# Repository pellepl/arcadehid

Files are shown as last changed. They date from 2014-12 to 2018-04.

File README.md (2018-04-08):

arcadehid
=========

STM32 HID device for arcade builds

Compound HID device containing keyboard, mouse, two joysticks and a virtual com port. Plug into a retropie or something and wire cool buttons and joysticks and whatnot.

See /cad - here you'll find a reference design with 26 pins for an STM32F1 128kB flash variant. Any STM32F1 board would do, as long as pin-headers are broken out.

Each pin can be configured with combinations of a keyboard keypress, mouse movement or click, or joystick movement or button press.

Every pin can hold up to eight different combinations. There is also ternary support meaning a pin's config can change depending on if another pin is active or not.

Accelerators for mouse and joystick are supported.

Everything is configured in the command line interface, either via UART pins or via virtual com port.

Different configurations can be saved and loaded, using the internal flash of the STM32F1 (128 kb variant) - no extra storage chip needed.

Depends on pellepl/generic_embedded and pellepl/niffs.

Now also with the Annoyatron support, drive your friends mad...

CLI pin definition examples
===========================
```
// define pin 1 to send keyboard character A
def pin1 = a
// define pin 2 to move mouse up
def pin2 = mouse_y(-1)
// define pin 3 to move mouse right if pin 4 is pressed else left
def pin3 = pin4 ? mouse_x(1) : mouse_x(-1)
// define pin 5 to send keyboard sequence CTRL+ALT+DEL
def pin5 = LEFT_CTRL LEFT_ALT DELETE
```

For certain definitions, numerators are possible. A numerators normally tells how much to move something, e.g. a mouse or joystick. In addition, all numerators can have accelerators, meaning the control will move more and more over time.
A numerator ```<num>``` is defined as  ```(ACC)[(+)|-][1..127]```.

```
// move joystick 10 steps right on x axis
def pin7 = joy1_x(10)
// move joystick accelerating from 1 to 10 steps right on x axis
def pin8 = joy1_x(ACC10)
// and left
def pin8 = joy1_x(ACC-10)
```

Accelerator speed is controlled by cli commands
```
set_mouse_pos_acc
set_mouse_wheel_acc
set_joy_acc
```

Following is a list of all definitions possible.

```
KEYBOARD SYMBOLS:
  A                   B                   C                   D                   
  E                   F                   G                   H                   
  I                   J                   K                   L                   
  M                   N                   O                   P                   
  Q                   R                   S                   T                   
  U                   V                   W                   X                   
  Y                   Z                   1                   2                   
  3                   4                   5                   6                   
  7                   8                   9                   0                   
  ENTER               ESCAPE              BACKSPACE           TAB                 
  SPACE               MINUS               EQUAL               LEFTBRACKET         
  RIGHTBRACKET        BACKSLASH           NONUS_HASH          SEMICOLON           
  QUOTE               GRAVE               COMMA               DOT                 
  SLASH               CAPSLOCK            F1                  F2                  
  F3                  F4                  F5                  F6                  
  F7                  F8                  F9                  F10                 
  F11                 F12                 PRINTSCREEN         SCROLLLOCK          
  PAUSE               INSERT              HOME                PGUP                
  DELETE              END                 PGDOWN              RIGHT               
  LEFT                DOWN                UP                  NUMLOCK             
  KP_SLASH            KP_ASTERISK         KP_MINUS            KP_PLUS             
  KP_ENTER            KP_1                KP_2                KP_3                
  KP_4                KP_5                KP_6                KP_7                
  KP_8                KP_9                KP_0                KP_DOT              
  NONUS_BACKSLASH     APPLICATION         POWER               KP_EQUAL            
  F13                 F14                 F15                 F16                 
  F17                 F18                 F19                 F20                 
  F21                 F22                 F23                 F24                 
  EXECUTE             HELP                MENU                SELECT              
  STOP                AGAIN               UNDO                CUT                 
  COPY                PASTE               FIND                MUTE                
  VOLUME_UP           VOLUME_DOWN         LOCKING_CAPS        LOCKING_NUM         
  LOCKING_SCROLL      KP_COMMA            KP_EQUAL_AS400      INT1                
  INT2                INT3                INT4                INT5                
  INT6                INT7                INT8                INT9                
  LANG1               LANG2               LANG3               LANG4               
  LANG5               LANG6               LANG7               LANG8               
  LANG9               ALT_ERASE           SYSREQ              CANCEL              
  CLEAR               PRIOR               RETURN              SEPARATOR           
  OUT                 OPER                CLEAR_AGAIN         CRSEL               
  EXSEL               SYSTEM_POWER        SYSTEM_SLEEP        SYSTEM_WAKE         
  AUDIO_MUTE          AUDIO_VOL_UP        AUDIO_VOL_DOWN      MEDIA_NEXT_TRACK    
  MEDIA_PREV_TRACK    MEDIA_STOP          MEDIA_PLAY_PAUSE    MEDIA_SELECT        
  MEDIA_EJECT         MAIL                CALCULATOR          MY_COMPUTER         
  WWW_SEARCH          WWW_HOME            WWW_BACK            WWW_FORWARD         
  WWW_STOP            WWW_REFRESH         WWW_FAVORITES       MEDIA_FAST_FORWARD  
  MEDIA_REWIND        LEFT_CTRL           LEFT_SHIFT          LEFT_ALT            
  LEFT_GUI            RIGHT_CTRL          RIGHT_SHIFT         RIGHT_ALT           
  RIGHT_GUI           

MOUSE SYMBOLS:
  MOUSE_X(<num>)      MOUSE_Y(<num>)      MOUSE_BUTTON1       MOUSE_BUTTON2       
  MOUSE_BUTTON3       MOUSE_WHEEL(<num>)  

JOYSTICK SYMBOLS:
  JOY1_X(<num>)       JOY1_Y(<num>)       JOY1_BUTTON1        JOY1_BUTTON2        
  JOY1_BUTTON3        JOY1_BUTTON4        JOY1_BUTTON5        JOY1_BUTTON6        
  JOY1_BUTTON7        JOY1_BUTTON8        JOY1_BUTTON9        JOY1_BUTTON10       
  JOY1_BUTTON11       JOY1_BUTTON12       JOY1_BUTTON13       JOY1_BUTTON14       
  JOY2_X(<num>)       JOY2_Y(<num>)       JOY2_BUTTON1        JOY2_BUTTON2        
  JOY2_BUTTON3        JOY2_BUTTON4        JOY2_BUTTON5        JOY2_BUTTON6        
  JOY2_BUTTON7        JOY2_BUTTON8        JOY2_BUTTON9        JOY2_BUTTON10       
  JOY2_BUTTON11       JOY2_BUTTON12       JOY2_BUTTON13       JOY2_BUTTON14
```

## Building ##

Make sure you clone submodules.

```
human-entity@machine ~$ git clone --recursive https://github.com/pellepl/arcadehid
```

You'll need an arm toolchain, let's say it lies in `/home/human-entity/toolchain/arm-none-eabi-toolchain-gcc-6.3.0`.
Then you simply do this:
```
human-entity@machine ~$ cd arcadehid
human-entity@machine ~/arcadehid$ make clean
human-entity@machine ~/arcadehid$ CROSS_COMPILE=/home/human-entity/toolchain/arm-none-eabi-toolchain-gcc-6.3.0/bin/arm-none-eabi- make all
```

Alternatively. you tinker a bit with the makefile.

This will produce target files in elf, binary, and ihex flavours in the `build` folder. Flash using your favourite dongle and tool. I use OpenOCD, there are some scripts in the repo which might be helpful to others.

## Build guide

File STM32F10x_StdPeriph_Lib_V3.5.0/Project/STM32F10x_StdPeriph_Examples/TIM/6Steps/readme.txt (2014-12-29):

/**
  @page TIM_6Steps TIM 6 Steps example
  
  @verbatim
  ******************** (C) COPYRIGHT 2011 STMicroelectronics *******************
  * @file    TIM/6Steps/readme.txt 
  * @author  MCD Application Team
  * @version V3.5.0
  * @date    08-April-2011
  * @brief   Description of the TIM 6 Steps example.
  ******************************************************************************
  * THE PRESENT FIRMWARE WHICH IS FOR GUIDANCE ONLY AIMS AT PROVIDING CUSTOMERS
  * WITH CODING INFORMATION REGARDING THEIR PRODUCTS IN ORDER FOR THEM TO SAVE
  * TIME. AS A RESULT, STMICROELECTRONICS SHALL NOT BE HELD LIABLE FOR ANY
  * DIRECT, INDIRECT OR CONSEQUENTIAL DAMAGES WITH RESPECT TO ANY CLAIMS ARISING
  * FROM THE CONTENT OF SUCH FIRMWARE AND/OR THE USE MADE BY CUSTOMERS OF THE
  * CODING INFORMATION CONTAINED HEREIN IN CONNECTION WITH THEIR PRODUCTS.
  ******************************************************************************
   @endverbatim

@par Example Description 

This example shows how to configure the TIM1 peripheral to generate 6 Steps.
The STM32F10x TIM1 peripheral offers the possibility to program in advance the 
configuration for the next TIM1 outputs behaviour (step) and change the configuration
of all the channels at the same time. This operation is possible when the COM 
(commutation) event is used.
The COM event can be generated by software by setting the COM bit in the TIM1_EGR
register or by hardware (on TRC rising edge).
In this example, a software COM event is generated each 100 ms: using the SysTick 
interrupt.
The TIM1 is configured in Timing Mode, each time a COM event occurs, a new TIM1
configuration will be set in advance.

The break Polarity is used at High level.

The following Table describes the TIM1 Channels states:
@verbatim
              -----------------------------------------------
             | Step1 | Step2 | Step3 | Step4 | Step5 | Step6 |
   ----------------------------------------------------------
  |Channel1  |   1   |   0   |   0   |   0   |   0   |   1   |
   ----------------------------------------------------------
  |Channel1N |   0   |   0   |   1   |   1   |   0   |   0   |
   ----------------------------------------------------------
  |Channel2  |   0   |   0   |   0   |   1   |   1   |   0   |
   ----------------------------------------------------------
  |Channel2N |   1   |   1   |   0   |   0   |   0   |   0   |
   ----------------------------------------------------------
  |Channel3  |   0   |   1   |   1   |   0   |   0   |   0   |
   ----------------------------------------------------------
  |Channel3N |   0   |   0   |   0   |   0   |   1   |   1   |
   ----------------------------------------------------------
 @endverbatim

@par Directory contents 

  - TIM/6Steps/stm32f10x_conf.h    Library Configuration file
  - TIM/6Steps/stm32f10x_it.c      Interrupt handlers
  - TIM/6Steps/stm32f10x_it.h      Interrupt handlers header file
  - TIM/6Steps/main.c              Main program
  - TIM/6Steps/system_stm32f10x.c  STM32F10x system source file
  
@par Hardware and Software environment 

  - This example runs on STM32F10x Connectivity line, High-Density, High-Density 
    Value line, Medium-Density, XL-Density, Medium-Density Value line, Low-Density 
    and Low-Density Value line Devices.
  
  - This example has been tested with STMicroelectronics STM32100E-EVAL (High-Density
    Value line), STM32100B-EVAL (Medium-Density Value line), STM3210C-EVAL (Connectivity line), 
    STM3210E-EVAL (High-Density and XL-Density) and STM3210B-EVAL (Medium-Density) 
    evaluation boards and can be easily tailored to any other supported device 
    and development board.

  - STM3210C-EVAL Set-up 
    - Connect the TIM1 pins(TIM1 full remapped pins) to an oscilloscope to monitor the different waveforms:
      - TIM1_CH3  pin (PE.13)
      - TIM1_CH1N pin (PE.08)  
      - TIM1_CH2  pin (PE.11)  
      - TIM1_CH3N pin (PE.12)
      - TIM1_CH1  pin (PE.09)  
      - TIM1_CH2N pin (PE.10)  
    - Connect the TIM1 break pin TIM1_BKIN pin (PE.15) to the GND. To generate a 
      break event, switch this pin level from 0V to 3.3V.     

  - STM3210E-EVAL, STM3210B-EVAL, STM32100B-EVAL and STM32100E-EVAL Set-up 
    - Connect the TIM1 pins to an oscilloscope to monitor the different waveforms:
      - TIM1_CH3  pin (PA.10)
      - TIM1_CH1N pin (PB.13)  
      - TIM1_CH2  pin (PA.09)  
      - TIM1_CH3N pin (PB.15)
      - TIM1_CH1  pin (PA.08)  
      - TIM1_CH2N pin (PB.14)    
    - Connect the TIM1 break pin TIM1_BKIN pin (PB.12) to the GND. To generate a 
      break event, switch this pin level from 0V to 3.3V. 

@par How to use it ? 

In order to make the program work, you must do the following :
 - Copy all source files from this example folder to the template folder under
   Project\STM32F10x_StdPeriph_Template
 - Open your preferred toolchain 
 - Rebuild all files and load your image into target memory
 - Run the example 

@note
 - Low-density Value line devices are STM32F100xx microcontrollers where the 
   Flash memory density ranges between 16 and 32 Kbytes.
 - Low-density devices are STM32F101xx, STM32F102xx and STM32F103xx 
   microcontrollers where the Flash memory density ranges between 16 and 32 Kbytes.
 - Medium-density Value line devices are STM32F100xx microcontrollers where
   the Flash memory density ranges between 64 and 128 Kbytes.  
 - Medium-density devices are STM32F101xx, STM32F102xx and STM32F103xx 
   microcontrollers where the Flash memory density ranges between 64 and 128 Kbytes.
 - High-density Value line devices are STM32F100xx microcontrollers where
   the Flash memory density ranges between 256 and 512 Kbytes.
 - High-density devices are STM32F101xx and STM32F103xx microcontrollers where
   the Flash memory density ranges between 256 and 512 Kbytes.
 - XL-density devices are STM32F101xx and STM32F103xx microcontrollers where
   the Flash memory density ranges between 512 and 1024 Kbytes.
 - Connectivity line devices are STM32F105xx and STM32F107xx microcontrollers.
   
 * <h3><center>&copy; COPYRIGHT 2011 STMicroelectronics</center></h3>
 */

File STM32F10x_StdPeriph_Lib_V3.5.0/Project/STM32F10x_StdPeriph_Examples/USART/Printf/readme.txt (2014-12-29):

/**
  @page USART_Printf USART Printf example
  
  @verbatim
  ******************** (C) COPYRIGHT 2011 STMicroelectronics *******************
  * @file    USART/Printf/readme.txt 
  * @author  MCD Application Team
  * @version V3.5.0
  * @date    08-April-2011
  * @brief   Description of the USART Printf example.
  ******************************************************************************
  * THE PRESENT FIRMWARE WHICH IS FOR GUIDANCE ONLY AIMS AT PROVIDING CUSTOMERS
  * WITH CODING INFORMATION REGARDING THEIR PRODUCTS IN ORDER FOR THEM TO SAVE
  * TIME. AS A RESULT, STMICROELECTRONICS SHALL NOT BE HELD LIABLE FOR ANY
  * DIRECT, INDIRECT OR CONSEQUENTIAL DAMAGES WITH RESPECT TO ANY CLAIMS ARISING
  * FROM THE CONTENT OF SUCH FIRMWARE AND/OR THE USE MADE BY CUSTOMERS OF THE
  * CODING INFORMATION CONTAINED HEREIN IN CONNECTION WITH THEIR PRODUCTS.
  ******************************************************************************
   @endverbatim

@par Example Description 

This example shows how to retarget the C library printf function to the USART. 
This implementation output the printf message on the Hyperterminal using USARTx.
USARTx can be USART1 or USART2 depending on the EVAL board you are using.

The USARTx is configured as follow:
    - BaudRate = 115200 baud  
    - Word Length = 8 Bits
    - One Stop Bit
    - No parity
    - Hardware flow control disabled (RTS and CTS signals)
    - Receive and transmit enabled

@par Directory contents 

  - USART/Printf/stm32f10x_conf.h     Library Configuration file
  - USART/Printf/stm32f10x_it.h       Interrupt handlers header file
  - USART/Printf/stm32f10x_it.c       Interrupt handlers
  - USART/Printf/main.c               Main program
  - USART/Printf/system_stm32f10x.c   STM32F10x system source file

@par Hardware and Software environment 

  - This example runs on STM32F10x Connectivity line, High-Density, High-Density 
    Value line, Medium-Density, XL-Density, Medium-Density Value line, Low-Density 
    and Low-Density Value line Devices.
  
  - This example has been tested with STMicroelectronics STM32100E-EVAL (High-Density
    Value line), STM32100B-EVAL (Medium-Density Value line), STM3210C-EVAL (Connectivity line), 
    STM3210E-EVAL (High-Density and XL-Density) and STM3210B-EVAL (Medium-Density) 
    evaluation boards and can be easily tailored to any other supported device 
    and development board.
    To select the STMicroelectronics evaluation board used to run the example, 
    uncomment the corresponding line in stm32_eval.h file (under Utilities\STM32_EVAL)

  - STM32100E-EVAL Set-up 
    - Connect a null-modem female/female RS232 cable between the DB9 connector 
     CN10 and PC serial port.
     
  - STM32100B-EVAL Set-up 
    - Connect a null-modem female/female RS232 cable between the DB9 connector 
     CN10 and PC serial port.  

  - STM3210C-EVAL Set-up 
    - Connect a null-modem female/female RS232 cable between the DB9 connector 
      CN6 (USART2) and PC serial port.
    @note Make sure that jumpers JP19 and JP18 are open.

  - STM3210E-EVAL Set-up
    - Connect a null-modem female/female RS232 cable between the DB9 connector 
      CN12(when USART1 is used) and PC serial port.   
   
  - STM3210B-EVAL Set-up  
    - Connect a null-modem female/female RS232 cable between the DB9 connector 
      CN6(when USART1 is used) and PC serial port.
	 
  - Hyperterminal configuration:
    - Word Length = 8 Bits
    - One Stop Bit
    - No parity
    - BaudRate = 115200 baud
    - flow control: None 

@par How to use it ? 

In order to make the program work, you must do the following :
 - Copy all source files from this example folder to the template folder under
   Project\STM32F10x_StdPeriph_Template
 - Open your preferred toolchain 
 - Rebuild all files and load your image into target memory
 - Run the example 

@note
 - Low-density Value line devices are STM32F100xx microcontrollers where the 
   Flash memory density ranges between 16 and 32 Kbytes.
 - Low-density devices are STM32F101xx, STM32F102xx and STM32F103xx 
   microcontrollers where the Flash memory density ranges between 16 and 32 Kbytes.
 - Medium-density Value line devices are STM32F100xx microcontrollers where
   the Flash memory density ranges between 64 and 128 Kbytes.  
 - Medium-density devices are STM32F101xx, STM32F102xx and STM32F103xx 
   microcontrollers where the Flash memory density ranges between 64 and 128 Kbytes.
 - High-density Value line devices are STM32F100xx microcontrollers where
   the Flash memory density ranges between 256 and 512 Kbytes.
 - High-density devices are STM32F101xx and STM32F103xx microcontrollers where
   the Flash memory density ranges between 256 and 512 Kbytes.
 - XL-density devices are STM32F101xx and STM32F103xx microcontrollers where
   the Flash memory density ranges between 512 and 1024 Kbytes.
 - Connectivity line devices are STM32F105xx and STM32F107xx microcontrollers.
   
 * <h3><center>&copy; COPYRIGHT 2011 STMicroelectronics</center></h3>
 */

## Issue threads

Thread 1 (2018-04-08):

BInary file?

M-e-i-k-e-l, 2018-04-08:
Dear Peter,

I've struggled with your arcadehid project to get it compiling with eclipse and ARM plugin, but I have still no success. It seems to be more complicated to solve all paths in the makefile to fit to the system here.
Very nice job you did! It would be nice to get it run on a 'blue pill' here on my workbench. :-D
Is it possible, that you send me a .hex or an .elf file?

Regards,
   Michael
   emailsiphon@freenet.de

pellepl, 2018-04-08:
Hi Michael,

I understand you had problems with this, as both projects on which arcadehid depends on have evolved further in life, while arcadehid has not.

Give me a few days and I'll see if I get arcadehid up to working status (can't even build it myself now). From there you should only have to change the gcc path. And, just to be safe, I'll also toss up the build artifacts.

pellepl, 2018-04-08:
That should do it. Added some info at end of the README.md. Are you planning to use this in an arcade box of some sort?

M-e-i-k-e-l, 2018-04-21:
Hi Peter,
I answered via github email replay, but it seems that they didn't arrive you.
So, I copy and paste them into this comment:

email#1 08.04.18:
thanks a lot! I will try your tips tomorrow, respectively this week.
I have left an Odroid C1+ here, it's task for WebDAV has been took over by a Pi3. I planned to realize a RetroPie or at least a C64 emulation with VICE. Big issue there is the (closed SW) GPU driver, up to now I cannot get a hardware rendered full screen.
In a first step it will be just a "flying" setup, no nice arcade housing. We will see.
Theoretically the two Competition Pro joysticks I bought on ebay could be implemented at the GPIOs of the C1, but with an blue pill as "adaptor" - maybe with a keyboard  in an old C64 housing additionally - I'm more flexible to try arcade emulations first on PC, too.
The blue pills here on the table I use for a project with step motors here, it will be a DIY 'clockclock' of http://www.humanssince1982.com/

email#2 09.04.18:
I got it compiling under Windows10 without issues. The path to the arm toolchain was a little bit challenging with spaces and "(x86)" in the default windows path name...
I've flashed it with CoxFlash on a blue pill (128k). No reaction on USB, plugging it in. I guess I have to exchange R10, my Blue Pills are populated with 10k instead of 1,5k.
As my project has an UART debugging port, too, I tried to communicate with putty via UART.
My question: What are the com parameters for UART and virtual com port?
9600 8N1?
115,2k?

Today's further work:
I changed to a Pi3 now, this savesd a lot of time...
Retropi is running VICE now and works like a charm.

I found the speed for UART2 with 460800 baud, but I want to use the Virtaul Com Device. I went through your config files in root src folder as well as the usb folder, but no clue.
On my Windows10 here the standard Serial-to-USB driver from microsoft is not working, finally it seems to work with the FTDI driver - a least the exclamation mark disappeared. The HID-Devices work with the microsoft HID driver.
So my question: What is the VCD baud rate? Hopefully the FTDI driver didn't fool me, I tried all popular baudrates from 1200 up to 128000 (even 460800, but I guess, this is not supported by windows) with putty.

Have a nice weekend!
Michael

M-e-i-k-e-l, 2018-04-28:
Ok, found it in src\usb\usb_prop.c:
115k2,8N1 in the linecoding definition.
So now I have to investigate, why it is not working here on the windows machine.
Regards; Michael

Closed 2018-04-08.

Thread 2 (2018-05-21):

analog joystick input

bschwand, 2018-05-21:
Hi,
This is not an actual issue, but I do not know how to communicate this any other way...

How hard would it be to also allow analog joystick input ? i.e. hook up a potentiometer, and the value sent corresponds. Ideally the configuration would also allow to specify on which pin (restricted by HW of course) the analog value is sampled, and then how it is scaled for example.

I wonder if this is a feature that has been considered, if there are any plans for it, and if not, how hard it would be for me to add it.

cheers !

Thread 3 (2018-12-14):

config_header.h problem

beastieboy, 2018-12-14:
The file config_header.h should be generated during make but it fails. Is it important?

pellepl, 2018-12-14:
If memory serves, yes. It is however only a reformatting of config.mk, making all variables defines. What's the error and what os are you compiling on?

beastieboy, 2018-12-15:
At the moment I try to compile it under MacOS. I don't think it's possible without radical config reformatting. The error I receive is like that:

```
bash-3.2$ CROSS_COMPILE=/Users/beastieboy/opt/gcc-arm-none-eabi-6-2017-q2-update/bin/arm-none-eabi- make all
... depend build/stm32f10x_it.d
In file included from ./src/system_config.h:11:0,
                 from gitsub/generic_embedded/src/system.h:11,
                 from src/stm32f10x_it.c:1:
./src/config_header.h:3:0: error: unterminated #ifndef
 #ifndef _CONFIG_HEADER_H

./src/config_header.h:2:0: error: unterminated #ifdef
 #ifdef INCLUDE_CONFIG_HEADER
```

This is a result of corrupt system_config.h which is not generated properly. Maybe you can just post here SDK/libraries versions you used to compile?

beastieboy, 2018-12-15:
And maybe you can give a small hint how to prepare STM32 board for this project, should I flash a special HID bootloader first?

beastieboy, 2018-12-19:
Compiles flawlessly under Ubuntu. Closing.

Closed 2018-12-19.

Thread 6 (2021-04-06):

Pin actions

NeoCortex97, 2021-04-06:
# Feature request.

I got Buttons with leds and I would like to be able to attach the leds to pins and control them.

## Example
Button A is a shift button and attached to pin 5. The LED for Button A is attached to pin 6. Button B is attached to pin 7 with the led on 8. Button C is on pin 9 and 10.
Button A is used as a shift key. If button A is pressed, Button B should light up, as it is the only one that has a second function.

I hope that would not be too much trouble. Please tell me if I missed this feature and it already exists.

beastieboy, 2022-01-20:
Hi, there's no such functionality in the code I studied and modified heavily for my own project. Adding it would be tricky and take a lot of testing. Additionally, there are bugs in the shift button code and I had to fix them.

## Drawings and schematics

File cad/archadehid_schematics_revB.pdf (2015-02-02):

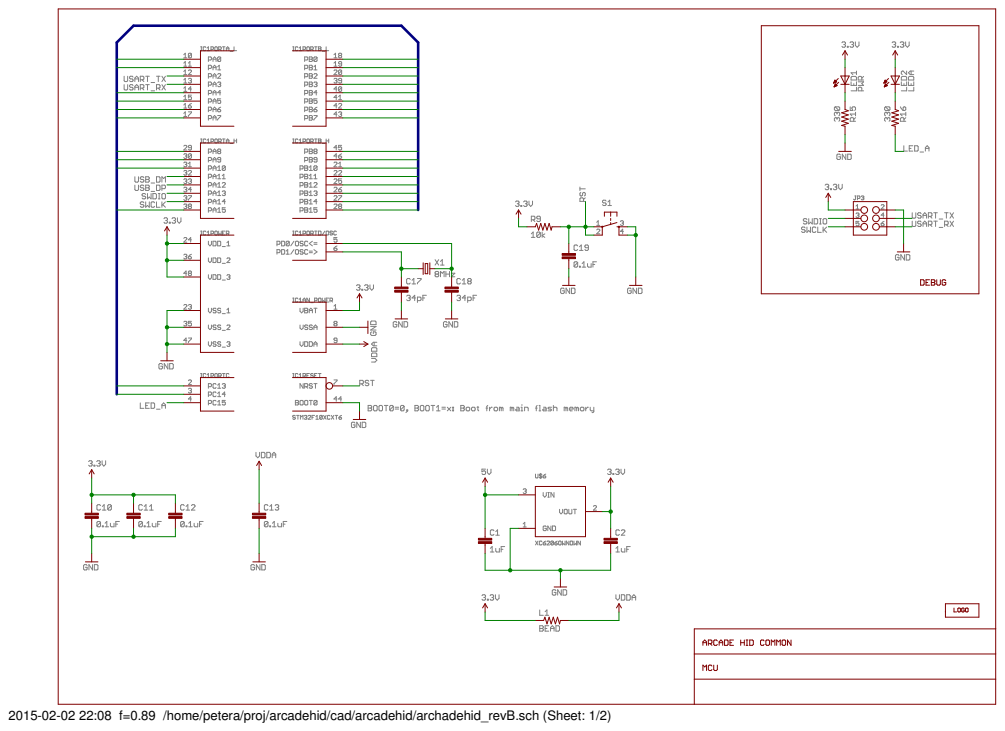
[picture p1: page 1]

2015-02-02 22:08 f=0.89 /home/petera/proj/arcadehid/cad/arcadehid/archadehid_revB.sch (Sheet: 1/2)

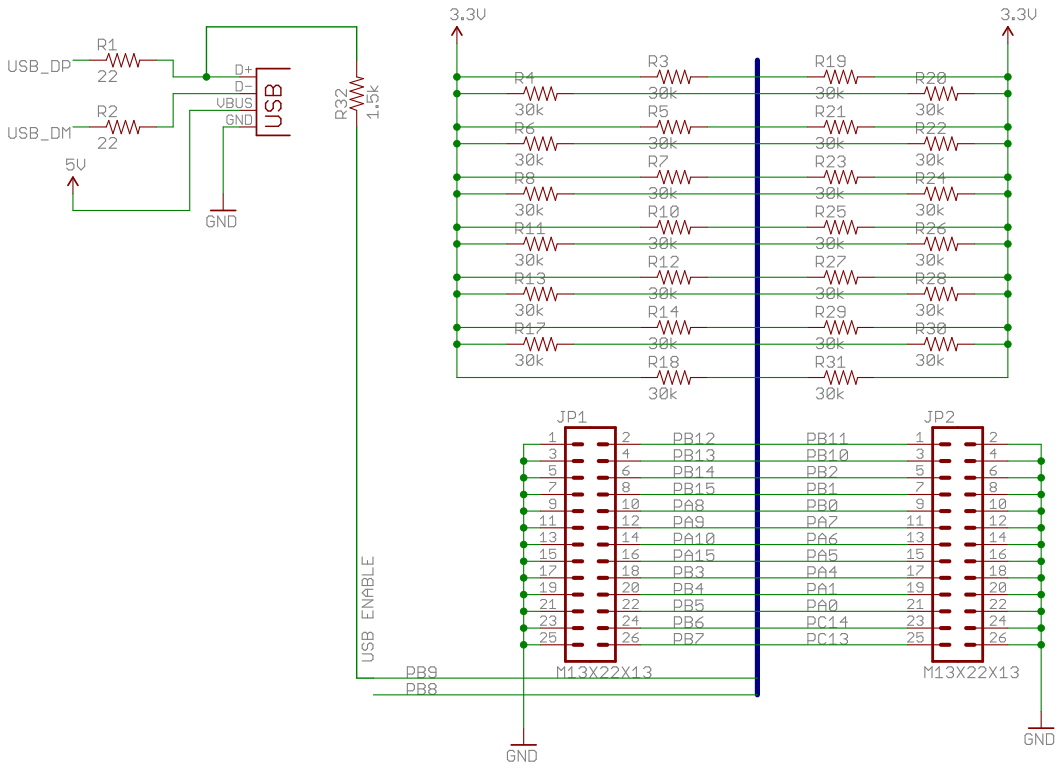
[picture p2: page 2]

2015-02-02 22:08 f=0.89 /home/petera/proj/arcadehid/cad/arcadehid/archadehid_revB.sch (Sheet: 2/2)

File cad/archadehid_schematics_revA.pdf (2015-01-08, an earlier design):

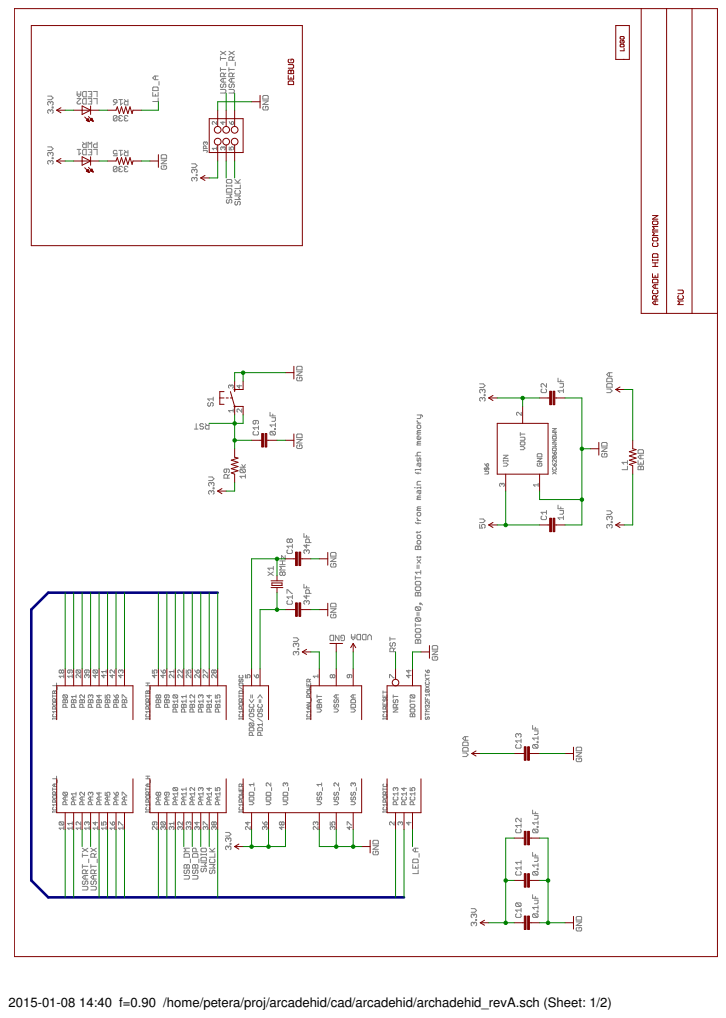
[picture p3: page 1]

2015-01-08 14:40 f=0.90 /home/petera/proj/arcadehid/cad/arcadehid/archadehid_revA.sch (Sheet: 1/2)

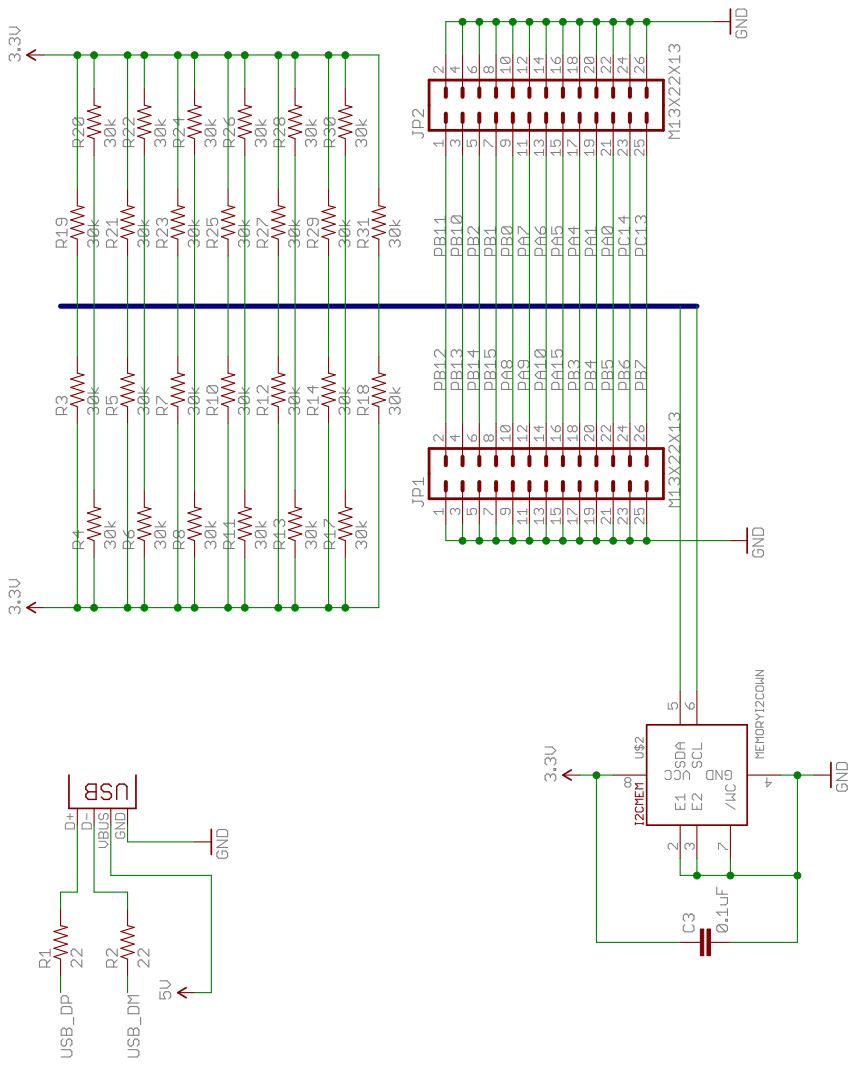
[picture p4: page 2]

2015-01-08 14:40 f=0.90 /home/petera/proj/arcadehid/cad/arcadehid/archadehid_revA.sch (Sheet: 2/2)

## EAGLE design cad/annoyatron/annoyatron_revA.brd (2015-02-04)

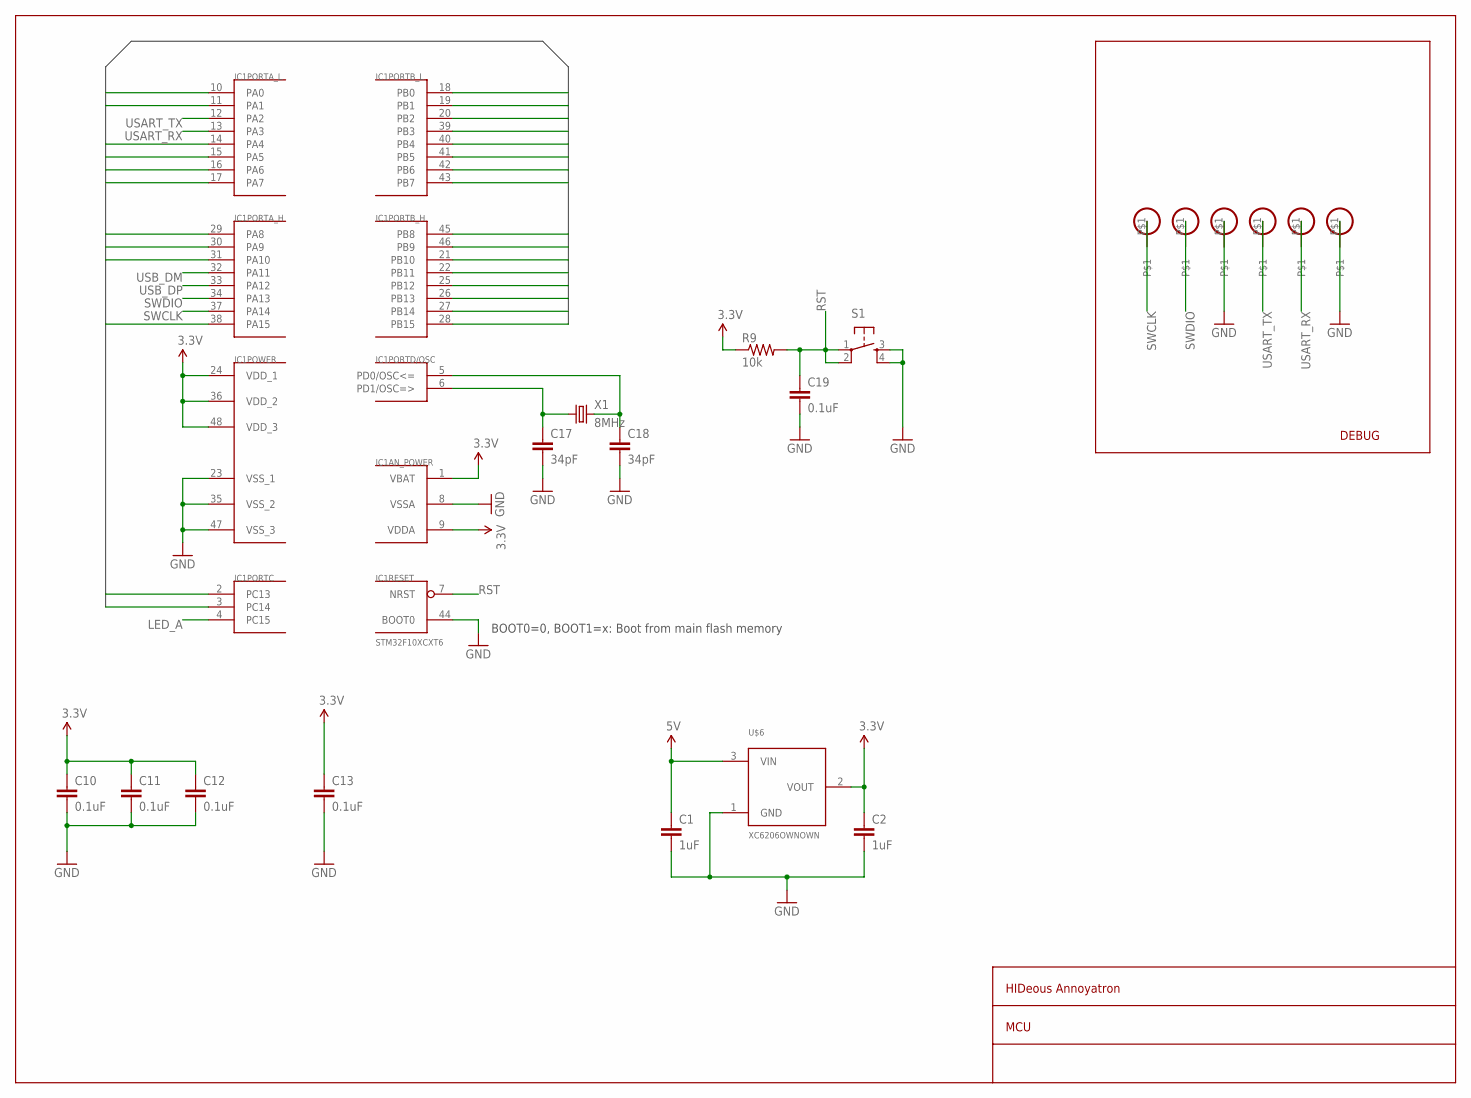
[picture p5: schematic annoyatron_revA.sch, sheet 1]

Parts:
C1, C2: 1uF; 0805_GEN
C10, C11, C12, C13, C19: 0.1uF; C0402
C17, C18: 34pF; C0402
IC1: STM32F10XCXT6; TQFP48
R9: 10k; C0402
S1: TAC_SWITCHSMD; TACTILE_SWITCH_SMD
U$2, U$3, U$4, U$5, U$9, U$10: PADOWN; PAD2MM
U$6: XC6206OWNOWN; SOT23
X1: 8MHz; CRYSTAL_SMD_5X3.2_7A

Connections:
3.3V: C2.1, C10.1, C11.1, C12.1, C13.1, IC1.1 (VBAT), IC1.9 (VDDA), IC1.24 (VDD_1), IC1.36 (VDD_2), IC1.48 (VDD_3), R9.1, U$6.2 (VOUT)
5V: C1.1, U$6.3 (VIN); also elsewhere on the board
GND: C1.2, C2.2, C10.2, C11.2, C12.2, C13.2, C17.2, C18.2, C19.2, IC1.8 (VSSA), IC1.23 (VSS_1), IC1.35 (VSS_2), IC1.44 (BOOT0), IC1.47 (VSS_3), S1.3, S1.4, U$4.P$1, U$6.1 (GND), U$10.P$1; also elsewhere on the board
LED_A: IC1.4 (PC15)
OSCI: C18.1, IC1.5 (PD0/OSC<=), X1.P$2 (2)
OSCO: C17.1, IC1.6 (PD1/OSC=>), X1.P$1 (1)
PA0: IC1.10 (PA0)
PA1: IC1.11 (PA1)
PA4: IC1.14 (PA4)
PA5: IC1.15 (PA5)
PA6: IC1.16 (PA6)
PA7: IC1.17 (PA7)
PA8: IC1.29 (PA8); also elsewhere on the board
PA9: IC1.30 (PA9)
PA10: IC1.31 (PA10)
PA15: IC1.38 (PA15)
PB0: IC1.18 (PB0)
PB1: IC1.19 (PB1)
PB2: IC1.20 (PB2)
PB3: IC1.39 (PB3)
PB4: IC1.40 (PB4)
PB5: IC1.41 (PB5)
PB6: IC1.42 (PB6)
PB7: IC1.43 (PB7)
PB8: IC1.45 (PB8)
PB9: IC1.46 (PB9)
PB10: IC1.21 (PB10)
PB11: IC1.22 (PB11)
PB12: IC1.25 (PB12)
PB13: IC1.26 (PB13)
PB14: IC1.27 (PB14)
PB15: IC1.28 (PB15)
PC13: IC1.2 (PC13)
PC14: IC1.3 (PC14)
RST: C19.1, IC1.7 (NRST), R9.2, S1.1, S1.2
SWCLK: IC1.37 (PA14), U$2.P$1
SWDIO: IC1.34 (PA13), U$3.P$1
USART_RX: IC1.13 (PA3), U$9.P$1
USART_TX: IC1.12 (PA2), U$5.P$1
USB_DM: IC1.32 (PA11); also elsewhere on the board
USB_DP: IC1.33 (PA12); also elsewhere on the board

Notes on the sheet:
HIDeous Annoyatron
MCU
DEBUG
BOOT0=0, BOOT1=x: Boot from main flash memory

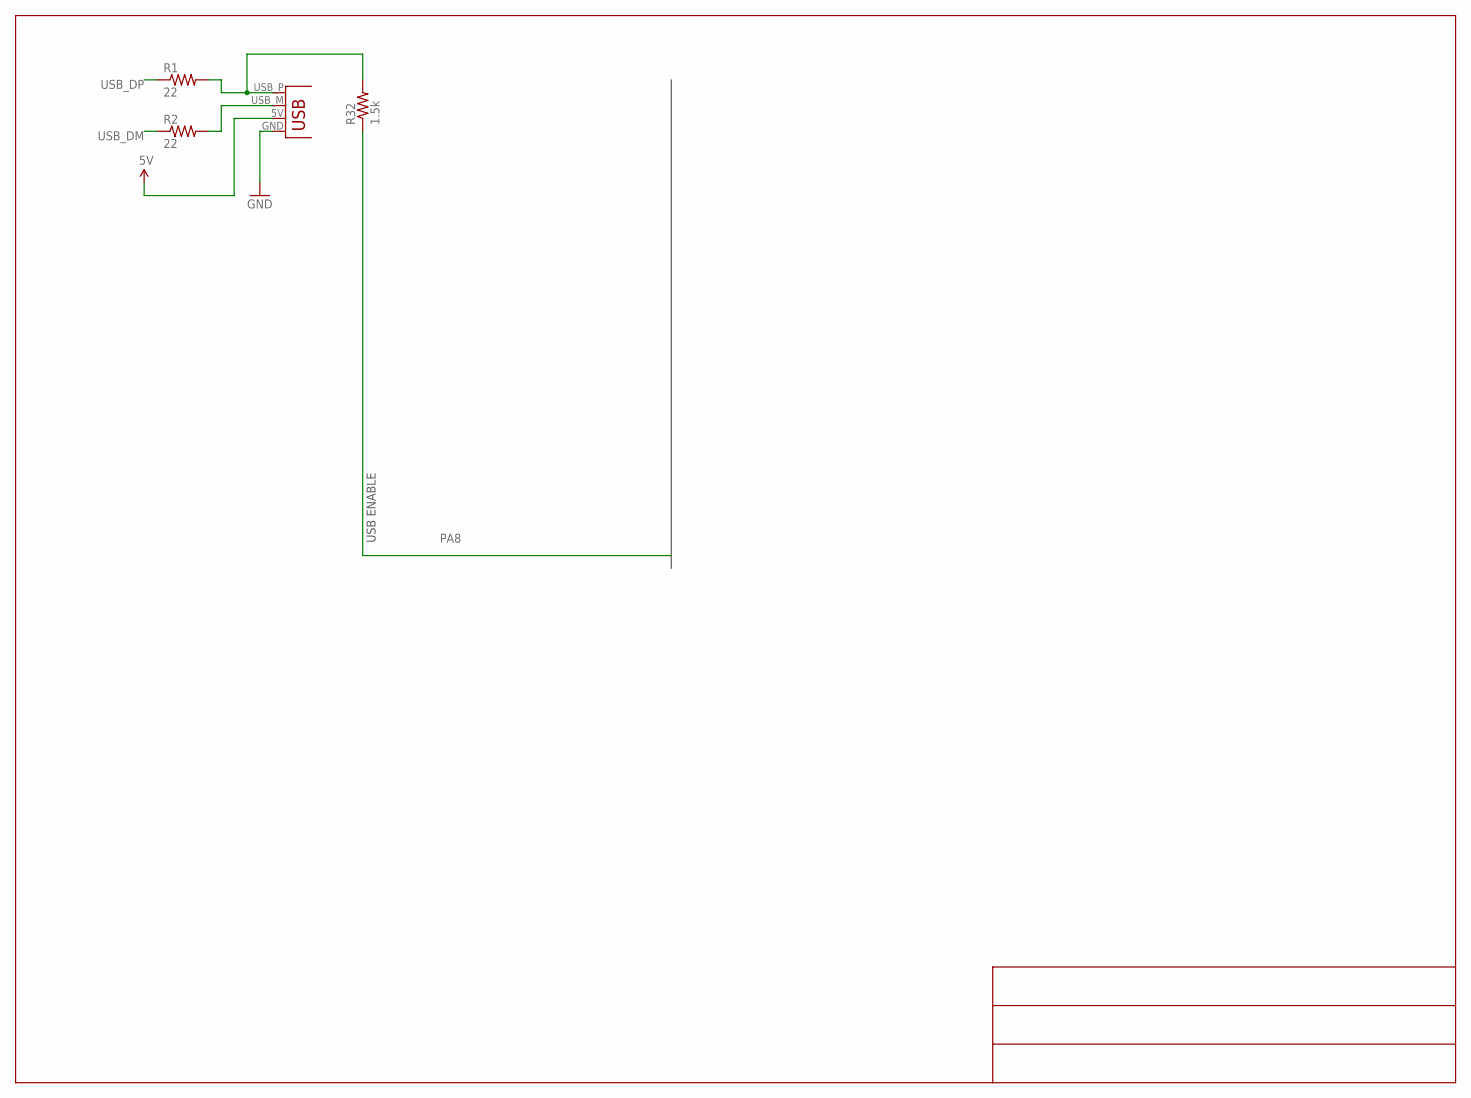
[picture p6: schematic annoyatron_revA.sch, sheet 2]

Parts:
JP1: USBPCB; USB-A-PCB
R1, R2: 22; C0402
R32: 1.5k; C0402

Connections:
5V: JP1.5V (VBUS); also elsewhere on the board
GND: JP1.GND; also elsewhere on the board
unnamed: JP1.USB_P (D+), R1.2, R32.2
unnamed: JP1.USB_M (D-), R2.2
PA8: R32.1; also elsewhere on the board
USB_DM: R2.1; also elsewhere on the board
USB_DP: R1.1; also elsewhere on the board

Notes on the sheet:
USB ENABLE

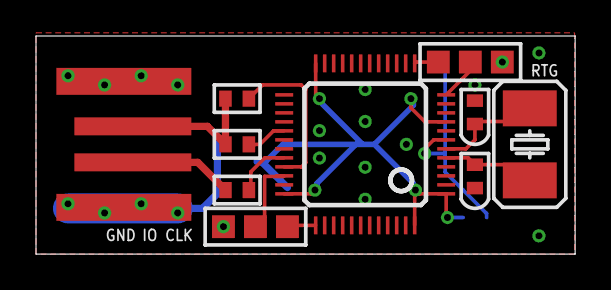
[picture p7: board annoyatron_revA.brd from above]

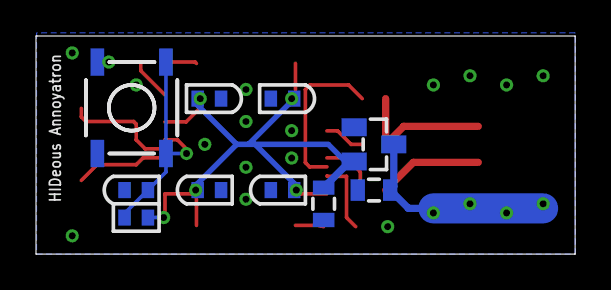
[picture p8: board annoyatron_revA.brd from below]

Board: 2 copper layers, 30.0 x 12.1 mm, 24 parts (10 on the bottom side), 15 nets.

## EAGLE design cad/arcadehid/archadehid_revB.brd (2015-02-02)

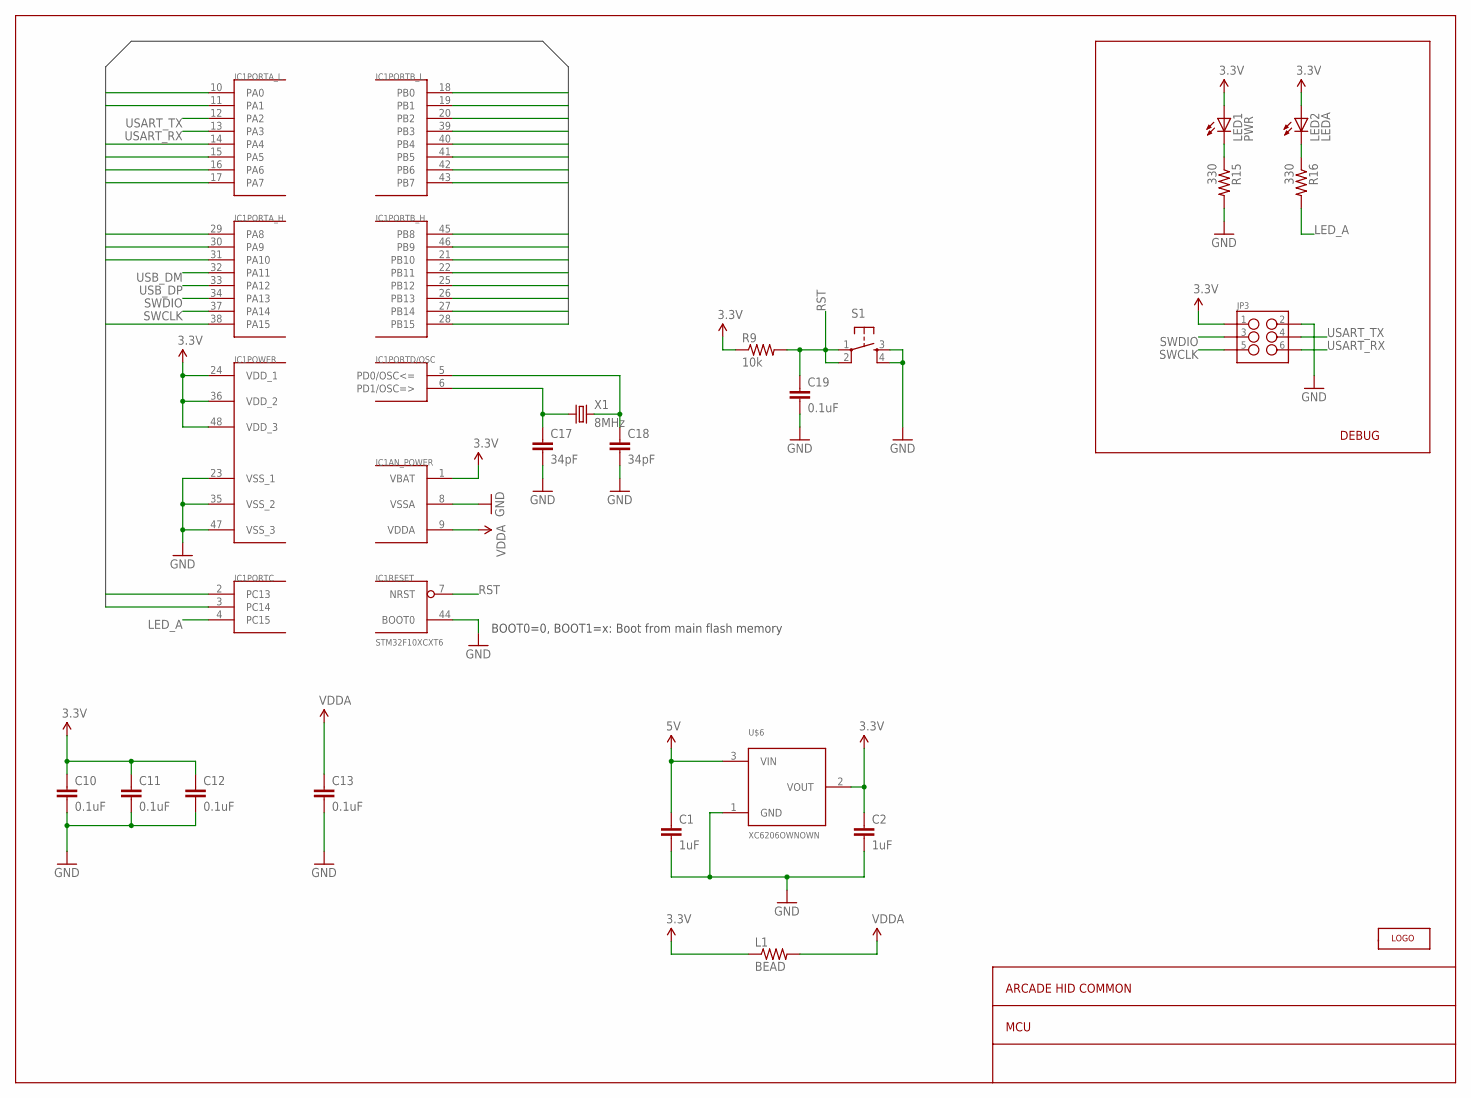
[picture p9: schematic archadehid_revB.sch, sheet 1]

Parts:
C1, C2: 1uF; 0805_GEN
C10, C11, C12, C13, C19: 0.1uF; C0402
C17, C18: 34pF; C0402
IC1: STM32F10XCXT6; TQFP48
JP3: M03X2NO_SILK; 2X3-NS
L1: BEAD; 0603_GEN
LED1: PWR; LED-0603
LED2: LEDA; LED-0603
R9: 10k; C0402
R15, R16: 330; C0402
S1: TAC_SWITCHSMD; TACTILE_SWITCH_SMD
U$6: XC6206OWNOWN; SOT23
U$7: LOGOLOGO; LOGO
X1: 8MHz; CRYSTAL_SMD_5X3.2_7A

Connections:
3.3V: C2.1, C10.1, C11.1, C12.1, IC1.1 (VBAT), IC1.24 (VDD_1), IC1.36 (VDD_2), IC1.48 (VDD_3), JP3.1, L1.1, LED1.A, LED2.A, R9.1, U$6.2 (VOUT); also elsewhere on the board
5V: C1.1, U$6.3 (VIN); also elsewhere on the board
GND: C1.2, C2.2, C10.2, C11.2, C12.2, C13.2, C17.2, C18.2, C19.2, IC1.8 (VSSA), IC1.23 (VSS_1), IC1.35 (VSS_2), IC1.44 (BOOT0), IC1.47 (VSS_3), JP3.2, R15.2, S1.3, S1.4, U$6.1 (GND); also elsewhere on the board
LED_A: IC1.4 (PC15), R16.2
unnamed: LED1.C, R15.1
unnamed: LED2.C, R16.1
OSCI: C18.1, IC1.5 (PD0/OSC<=), X1.P$2 (2)
OSCO: C17.1, IC1.6 (PD1/OSC=>), X1.P$1 (1)
PA0: IC1.10 (PA0); also elsewhere on the board
PA1: IC1.11 (PA1); also elsewhere on the board
PA4: IC1.14 (PA4); also elsewhere on the board
PA5: IC1.15 (PA5); also elsewhere on the board
PA6: IC1.16 (PA6); also elsewhere on the board
PA7: IC1.17 (PA7); also elsewhere on the board
PA8: IC1.29 (PA8); also elsewhere on the board
PA9: IC1.30 (PA9); also elsewhere on the board
PA10: IC1.31 (PA10); also elsewhere on the board
PA15: IC1.38 (PA15); also elsewhere on the board
PB0: IC1.18 (PB0); also elsewhere on the board
PB1: IC1.19 (PB1); also elsewhere on the board
PB2: IC1.20 (PB2); also elsewhere on the board
PB3: IC1.39 (PB3); also elsewhere on the board
PB4: IC1.40 (PB4); also elsewhere on the board
PB5: IC1.41 (PB5); also elsewhere on the board
PB6: IC1.42 (PB6); also elsewhere on the board
PB7: IC1.43 (PB7); also elsewhere on the board
PB8: IC1.45 (PB8)
PB9: IC1.46 (PB9); also elsewhere on the board
PB10: IC1.21 (PB10); also elsewhere on the board
PB11: IC1.22 (PB11); also elsewhere on the board
PB12: IC1.25 (PB12); also elsewhere on the board
PB13: IC1.26 (PB13); also elsewhere on the board
PB14: IC1.27 (PB14); also elsewhere on the board
PB15: IC1.28 (PB15); also elsewhere on the board
PC13: IC1.2 (PC13); also elsewhere on the board
PC14: IC1.3 (PC14); also elsewhere on the board
RST: C19.1, IC1.7 (NRST), R9.2, S1.1, S1.2
SWCLK: IC1.37 (PA14), JP3.5
SWDIO: IC1.34 (PA13), JP3.3
USART_RX: IC1.13 (PA3), JP3.6
USART_TX: IC1.12 (PA2), JP3.4
USB_DM: IC1.32 (PA11); also elsewhere on the board
USB_DP: IC1.33 (PA12); also elsewhere on the board
VDDA: C13.1, IC1.9 (VDDA), L1.2

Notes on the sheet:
ARCADE HID COMMON
MCU
DEBUG
BOOT0=0, BOOT1=x: Boot from main flash memory

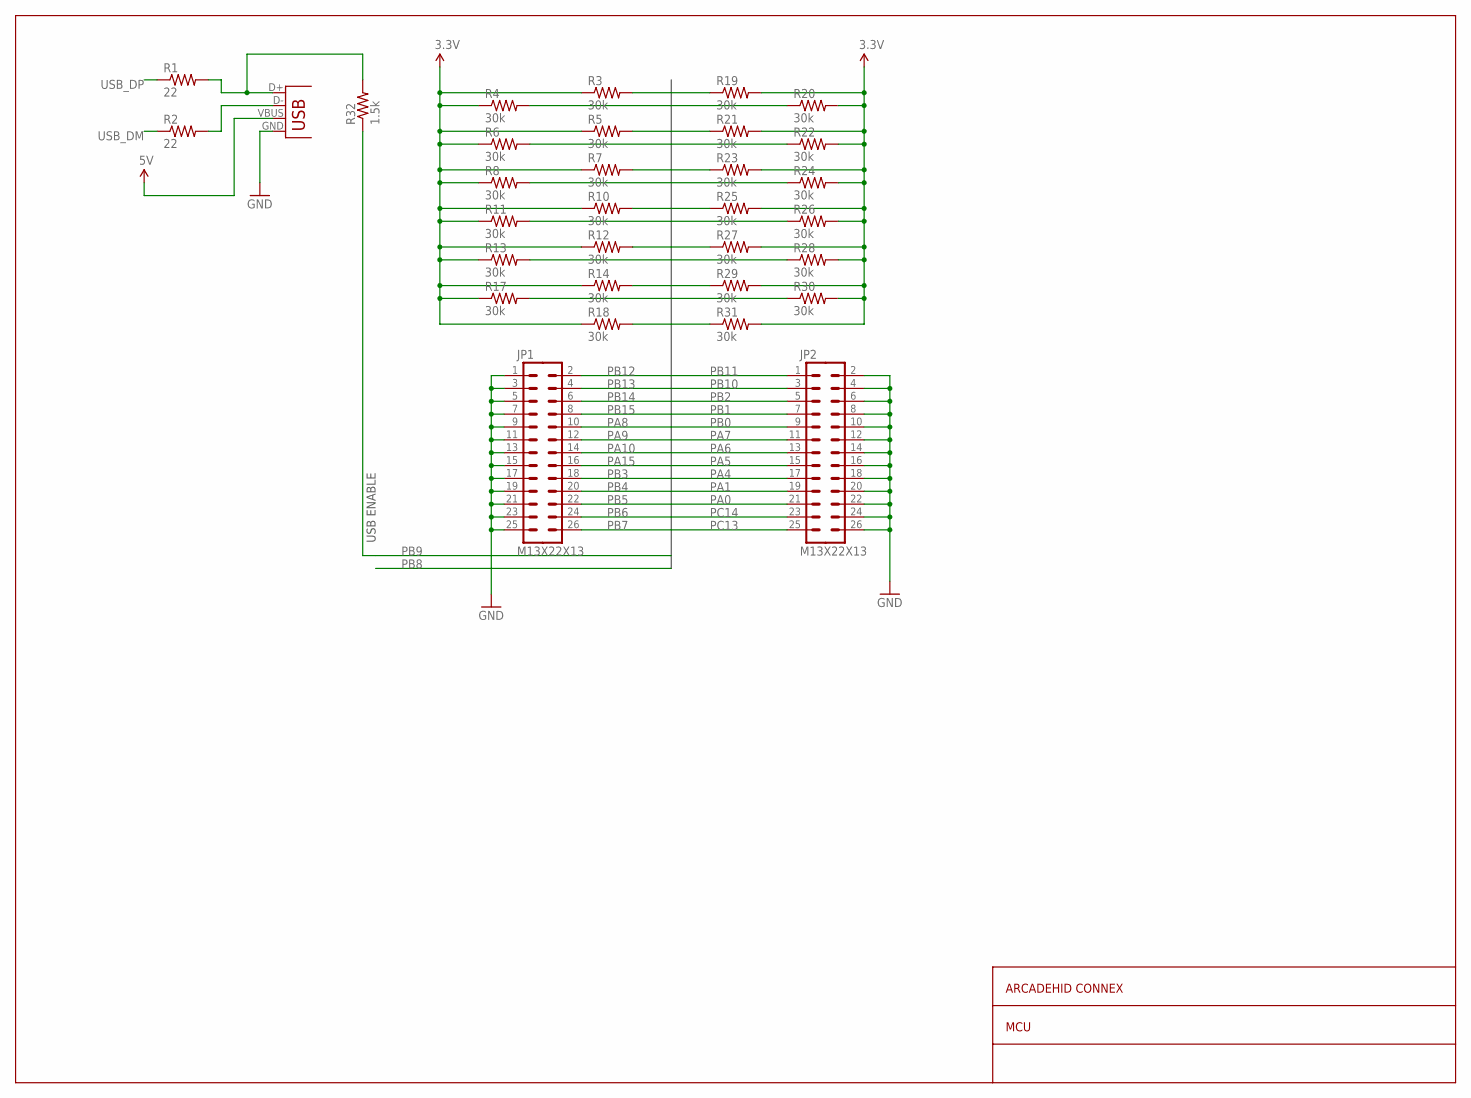
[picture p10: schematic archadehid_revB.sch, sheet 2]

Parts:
JP1, JP2: M13X22X13; 2X13
R1, R2: 22; C0402
R3, R4, R5, R6, R7, R8, R10, R11, R12, R13, R14, R17, R18, R19, R20, R21, R22, R23, R24, R25, R26, R27, R28, R29, R30, R31: 30k; C0402
R32: 1.5k; C0402
X3: USB-MINIB

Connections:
3.3V: R3.1, R4.1, R5.1, R6.1, R7.1, R8.1, R10.1, R11.1, R12.1, R13.1, R14.1, R17.1, R18.1, R19.2, R20.2, R21.2, R22.2, R23.2, R24.2, R25.2, R26.2, R27.2, R28.2, R29.2, R30.2, R31.2; also elsewhere on the board
5V: X3.VBUS; also elsewhere on the board
GND: JP1.1, JP1.3, JP1.5, JP1.7, JP1.9, JP1.11, JP1.13, JP1.15, JP1.17, JP1.19, JP1.21, JP1.23, JP1.25, JP2.2, JP2.4, JP2.6, JP2.8, JP2.10, JP2.12, JP2.14, JP2.16, JP2.18, JP2.20, JP2.22, JP2.24, JP2.26, X3.GND; also elsewhere on the board
unnamed: R1.2, R32.2, X3.D+
unnamed: R2.2, X3.D-
PA0: JP2.21, R29.1; also elsewhere on the board
PA1: JP2.19, R28.1; also elsewhere on the board
PA4: JP2.17, R27.1; also elsewhere on the board
PA5: JP2.15, R26.1; also elsewhere on the board
PA6: JP2.13, R25.1; also elsewhere on the board
PA7: JP2.11, R24.1; also elsewhere on the board
PA8: JP1.10, R7.2; also elsewhere on the board
PA9: JP1.12, R8.2; also elsewhere on the board
PA10: JP1.14, R10.2; also elsewhere on the board
PA15: JP1.16, R11.2; also elsewhere on the board
PB0: JP2.9, R23.1; also elsewhere on the board
PB1: JP2.7, R22.1; also elsewhere on the board
PB2: JP2.5, R21.1; also elsewhere on the board
PB3: JP1.18, R12.2; also elsewhere on the board
PB4: JP1.20, R13.2; also elsewhere on the board
PB5: JP1.22, R14.2; also elsewhere on the board
PB6: JP1.24, R17.2; also elsewhere on the board
PB7: JP1.26, R18.2; also elsewhere on the board
PB9: R32.1; also elsewhere on the board
PB10: JP2.3, R20.1; also elsewhere on the board
PB11: JP2.1, R19.1; also elsewhere on the board
PB12: JP1.2, R3.2; also elsewhere on the board
PB13: JP1.4, R4.2; also elsewhere on the board
PB14: JP1.6, R5.2; also elsewhere on the board
PB15: JP1.8, R6.2; also elsewhere on the board
PC13: JP2.25, R31.1; also elsewhere on the board
PC14: JP2.23, R30.1; also elsewhere on the board
USB_DM: R2.1; also elsewhere on the board
USB_DP: R1.1; also elsewhere on the board

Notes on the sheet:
ARCADEHID CONNEX
MCU
USB ENABLE

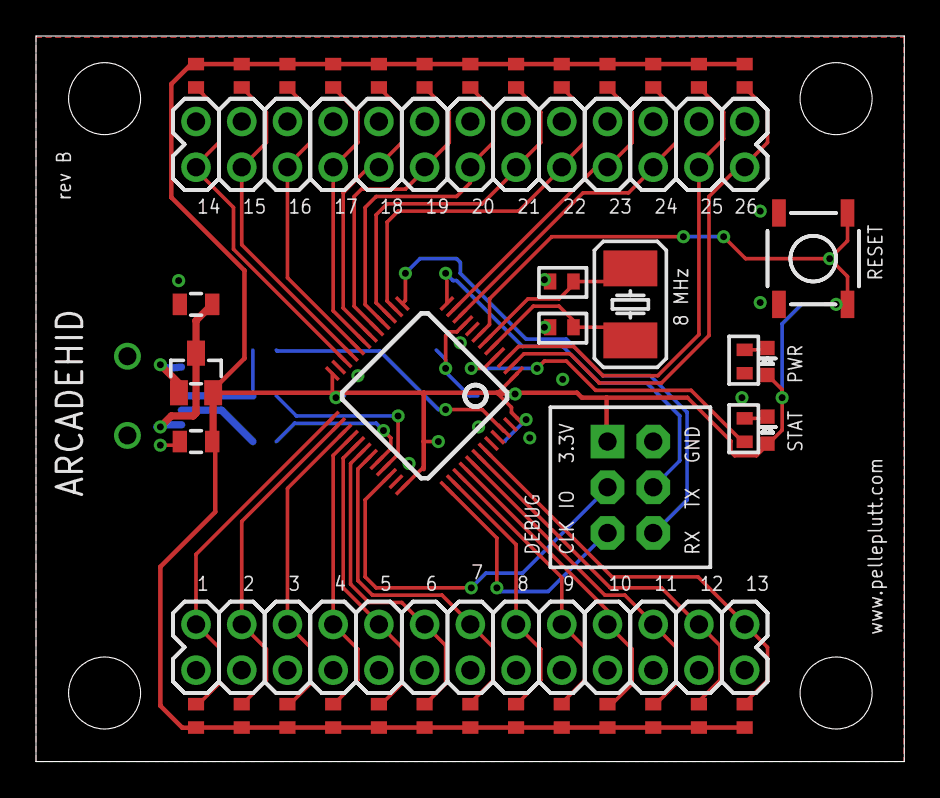
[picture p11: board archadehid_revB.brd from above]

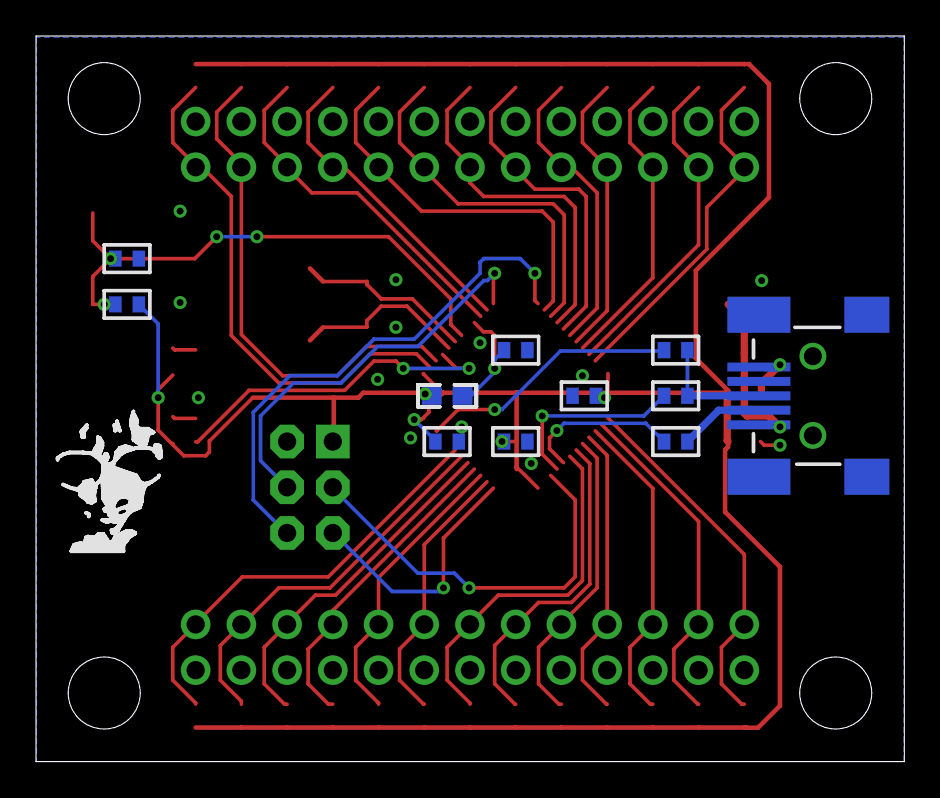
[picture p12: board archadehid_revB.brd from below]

Board: 2 copper layers, 48.2 x 40.3 mm, 53 parts (12 on the bottom side), 45 nets.

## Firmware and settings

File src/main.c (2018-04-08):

#include "stm32f10x.h"
#include "system.h"
#include "uart_driver.h"
#include "io.h"
#include "timer.h"
#include "miniutils.h"
#include "taskq.h"
#include "cli.h"
#include "processor.h"
#include "linker_symaccess.h"
#include "app.h"
#include "gpio.h"
#include "usb/usb_arcade.h"

static void assert_cb(void) {
  set_print_output(IOSTD);
//  uint32_t ipsr;
//  asm volatile ("MRS %0, ipsr" : "=r" (ipsr) );
//  print("IPSR 0x%02x\nBPRI 0x%02x\n", ipsr, __get_BASEPRI());
}

// main entry from bootstrap

int main(void) {
  enter_critical();
  PROC_base_init();
  SYS_init();
  UART_init();
  UART_assure_tx(_UART(0), TRUE);
  //UART_sync_tx(_UART(0), TRUE);
  PROC_periph_init();
  exit_critical();

  SYS_set_assert_callback(assert_cb);
  SYS_set_assert_behaviour(ASSERT_RESET);

  IO_define(IOSTD, io_uart, UARTSTDIN);
#ifndef CONFIG_ANNOYATRON
  IO_define(IOUSB, io_usb, -1);
#endif

  USB_ARC_init();

  print("\n\n\nHardware initialization done\n");

  print("Stack 0x%08x -- 0x%08x\n", STACK_START, STACK_END);

  print("Subsystem initialization done\n");

  TASK_init();

  CLI_init();

  rand_seed(0xd0decaed ^ SYS_get_tick());

  APP_init();

  while (1) {
    while (TASK_tick());
    TASK_wait();
  }

  return 0;
}

void assert_failed(uint8_t* file, uint32_t line) {
  SYS_assert((char*)file, (s32_t)line);
}

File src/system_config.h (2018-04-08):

/*
 * system_config.h
 *
 *  Created on: Jul 24, 2012
 *      Author: petera
 */

#ifndef SYSTEM_CONFIG_H_
#define SYSTEM_CONFIG_H_

#include "config_header.h"
#include "types.h"
#include "stm32f10x.h"

#ifndef CONFIG_ANNOYATRON
#define APP_NAME "ARCADEHID"
#else
#define APP_NAME "ANNOYATRON"
#endif


#define time sys_time

/****************************************/
/***** Functionality block settings *****/
/****************************************/

// enable uart2
#define CONFIG_UART2

#define CONFIG_UART_CNT   1 // update according to enabled uarts


/*********************************************/
/***** Hardware build time configuration *****/
/*********************************************/

/** Processor specifics **/

#ifndef USER_HARDFAULT
// enable user hardfault handler
#define USER_HARDFAULT 1
#endif

// hardware debug (blinking leds etc)
#define HW_DEBUG


/** General **/

// internal flash start address
#define FLASH_START       FLASH_BASE
// internal flash page erase size
#define FLASH_PAGE_SIZE   0x400 // md
// internal flash protection/unprotection for firmware
#define FLASH_PROTECT     FLASH_WRProt_AllPages
// internal flash total size in bytes
#define FLASH_TOTAL_SIZE  (128*1024) // md

/** UART **/

#ifdef CONFIG_UART2
#define UART2_GPIO_PORT       GPIOA
#define UART2_GPIO_RX         GPIO_Pin_3
#define UART2_GPIO_TX         GPIO_Pin_2
#endif

/** USB STUFF **/
#define ID1                                 (0x1FFFF7E8)
#define ID2                                 (0x1FFFF7EC)
#define ID3                                 (0x1FFFF7F0)

/** I2C **/
#define I2C_MAX_ID            1
#define I2C1_PORT             I2C1

/****************************************************/
/******** Application build time configuration ******/
/****************************************************/

/** TICKER **/
// STM32 system timer
#define CONFIG_STM32_SYSTEM_TIMER   2
// system timer frequency
#define SYS_MAIN_TIMER_FREQ   10000
// system timer counter type
typedef u16_t system_counter_type;
// system tick frequency
#define SYS_TIMER_TICK_FREQ   1000
// os ticker cpu clock div
#define SYS_OS_TICK_DIV       8

/** PRINT **/
void arcprint(const char* f, ...);
void set_print_output(u8_t io);
u8_t get_print_output(void);

#define print(...) arcprint(__VA_ARGS__)

/** UART **/

#define UARTSTDIN       0
#define UARTSTDOUT      0

#define UART2_SPEED 460800

#define USE_COLOR_CODING

//#define CONFIG_ANNOYATRON

#ifndef CONFIG_ANNOYATRON
#define CONFIG_ARCHID_VCD
#endif // CONFIG_ANNOYATRON

/** IO **/
#define CONFIG_IO_MAX   2

#define IOSTD        0
#define IODBG        IOSTD
#define IOUSB        1

/** MATH **/
//#define CONFIG_TRIGQ_TABLE

/** TASK KERNEL **/
#define CONFIG_TASK_POOL 32
//#define CONFIG_TASK_NONCRITICAL_TIMER
//#define CONFIG_TASKQ_DBG_CRITICAL
#define CONFIG_TASKQ_MUTEX

/** USB **/

#define USB_KB_REPORT_KEYMAP_SIZE     32 /* 6 */

/** APP CONFIG **/

#ifdef CONFIG_HY_TEST_BOARD
#define APP_CONFIG_PINS               4
#else
#define APP_CONFIG_PINS               26
#endif
#define APP_CONFIG_DEFS_PER_PIN       8


/** DEBUG **/

#define DBG_ATTRIBUTE __attribute__(( section(".shmem") ))

// disable all asserts
//#define ASSERT_OFF

// disable all debug output
//#define DBG_OFF

#define CONFIG_DEFAULT_DEBUG_MASK     (0xffffffff)

// enable or disable tracing
#define DBG_TRACE_MON
#define TRACE_SIZE            (64)

#define VALID_RAM(x) \
  (((void*)(x) >= RAM_BEGIN && (void*)(x) < RAM_END))

#define VALID_FLASH(x) \
  ((void*)(x) >= (void*)FLASH_BEGIN && (void*)(x) < (void*)(FLASH_END))

#define VALID_DATA(x) \
  (VALID_RAM(x) || VALID_FLASH(x))

#define OS_DBG_BADR(x) \
    (!VALID_RAM(x))


#endif /* SYSTEM_CONFIG_H_ */

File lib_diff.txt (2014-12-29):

STM32F10x_StdPeriph_Lib_V3.5.0/Libraries/CMSIS/CM3/CoreSupport/core_cm3.c

  inline asm error, making strexb strexh use destination and result for same register - illegal

  --     __ASM volatile ("strexb %0, %2, [%1]" : "=r" (result) : "r" (addr), "r" (value) );
  ++     __ASM volatile ("strexb %0, %2, [%1]" : "=&r" (result) : "r" (addr), "r" (value) );
  --     __ASM volatile ("strexh %0, %2, [%1]" : "=r" (result) : "r" (addr), "r" (value) );
  ++     __ASM volatile ("strexh %0, %2, [%1]" : "=&r" (result) : "r" (addr), "r" (value) );
  


STM32F10x_StdPeriph_Lib_V3.5.0/Libraries/CMSIS/CM3/DeviceSupport/ST/STM32F10X/stm32f10x.h

  stdint.h not existing, instead include types.h typedeffing whats needed (uint8_t, etc)

  --   #include <stdint.h>
  ++   #include "types.h"  



STM32F10x_StdPeriph_Lib_V3.5.0/Libraries/CMSIS/CM3/DeviceSupport/ST/STM32F10X/startup/gcc_ride7/startup_stm32f10x_*.s

  Otherwise Reset_Vector will end up having even address in bootvectors, which will go HardFault
  
        .type  Reset_Handler, %function
  ++    .thumb_func
      Reset_Handler:  

      /* Copy the data segment initializers from flash to SRAM */  
        movs  r1, #0
  

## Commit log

2014-12-29 inital commit
    [archadehid_revA.brd, archadehid_revA.sch, lib_diff.txt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]
2014-12-29 cleanup, reset @ assert
    [cli.c, main.c, system_config.h]
2014-12-30 getting ledstate
2015-01-07 cadding, almost there
    [archadehid_revA.brd, archadehid_revA.sch]
2015-01-08 cad, rev A to factory
    [archadehid_revA.brd, archadehid_revA.sch]
2015-01-25 gpio deffing, key handling - still bugs, sticky keys
    [app.c, cli.c, gpio_map.c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]
2015-01-26 fixed gpiotrigging error, trigger on state instead of debouncer
    [app.c]
2015-02-01 added board rev A scripts and dbg, fixed accelerator and mouse
    [archid_jtag.cfg, archid_stlinkv2.cfg, spybot_stlinkv2.cfg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]
2015-02-01 fixed hy board jtag PB3, cleaned upp cli, added help texts
    [cli.c, processor.c]
2015-02-02 cad, rev B
    [archadehid_revB.brd, archadehid_revB.sch]
2015-02-04 cadded the annoyatron
    [annoyatron_revA.brd, annoyatron_revA.sch]
2015-02-06 added app glue for joystick control
2015-02-08 joystick almost working, needs resetting also (flank & level)
    [app.c, main.c]
2015-02-28 file system support, some bug fixing
    [cli.c, niffs_impl.c]
2015-03-02 default config, redesign of pinhandling started
    [app.c]
2015-03-23 more annoy scripts, fixed a cli bug when scripting
    [cli.c, system_config.h]

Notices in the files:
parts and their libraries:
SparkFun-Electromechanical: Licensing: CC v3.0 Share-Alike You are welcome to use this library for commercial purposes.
